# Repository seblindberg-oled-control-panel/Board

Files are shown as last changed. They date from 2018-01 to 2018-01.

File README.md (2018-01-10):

# OLED Control Panel Board

Mechanical design front
Mechanical design side

## Revisions

Board revisions are kept as tags in git. The board is generally tagged when the files have been sent off for manufacturing. To export a specific revision, simply run

```
$ git archive --format zip -o /path/to/rev-a.zip 9e7148
```

where the hash of the tag can be found by running `git show rev-a` for the specific tag.

## Scripts

A ruby script is included for generating EAGLE commands that place some of the more repetitive components. There are tools in EAGLE for achieving the same thing and they are most likely better, but a) I did not know that at the time and b) doing it yourself is often more flexible. 

To run the scripts you need to locate the Scripts folder in your terminal of choice and type `ruby place_leds.rb`. Then press `enter` and copy the output into the command input in EAGLE.

## Docs

The documentation is located in another repository and included here as a submodule. To get it after cloning you need to run

```
$ git submodule init
$ git submodule update
```

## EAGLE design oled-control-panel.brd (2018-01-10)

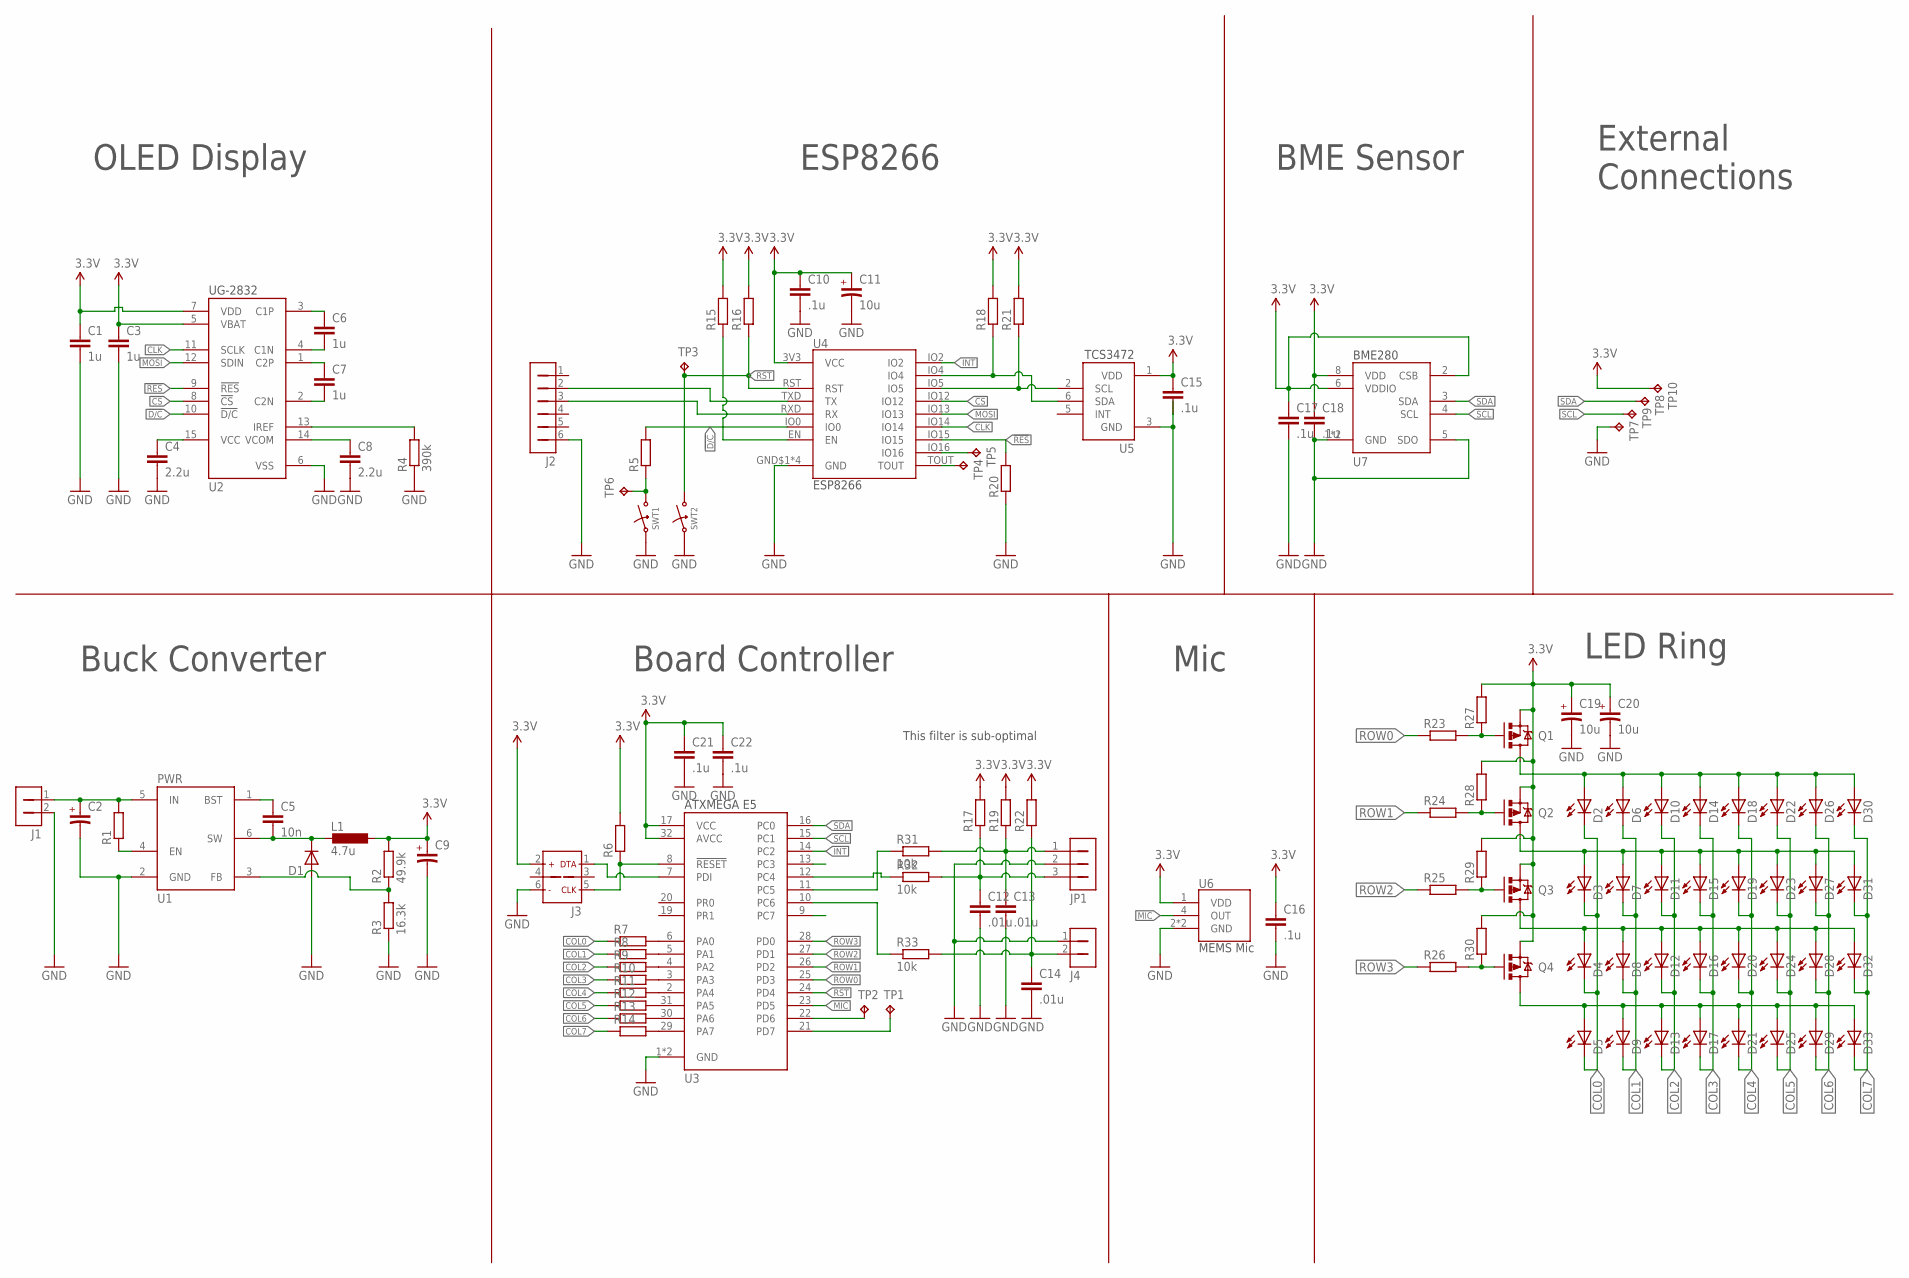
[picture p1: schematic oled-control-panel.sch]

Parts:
C1, C3, C6, C7: 1u; 0805
C2, C9: C_POL_1206; 1206_POL
C4, C8: 2.2u; 0805
C5: 10n; 0805
C10, C15, C16, C17, C18, C21, C22: .1u; 0603
C11, C19, C20: 10u; 1206_POL
C12, C13, C14: .01u; 0805
D1: D_FM581X; DO-214AC
D2, D3, D4, D5, D6, D7, D8, D9, D10, D11, D12, D13, D14, D15, D16, D17, D18, D19, D20, D21, D22, D23, D24, D25, D26, D27, D28, D29, D30, D31, D32, D33: LED_0805; 0805_LED
J1, J4: 1X2_MOLEX_53254
J2: 1X6_SMD_RIGHT
J3: PDI_SMD; ISP_SMD
JP1: 1X3_MOLEX_53254
L1: 4.7u; 1210
Q1, Q2, Q3, Q4: PMV160UP; SOT23
R1: R_0805; 0805
R2: 49.9k; 0805
R3: 16.3k; 0805
R4: 390k; 0805
R5, R6, R7, R8, R9, R10, R11, R12, R13, R14, R15, R16, R17, R18, R19, R20, R21, R22, R23, R24, R25, R26, R27, R28, R29, R30: R_0603; 0603
R31, R32, R33: 10k; 0603
SWT1, SWT2: BUTTON_SMD_2P; BTN_SMD_2PIN
TP1, TP2, TP3, TP4, TP5, TP6, TP7, TP8, TP9, TP10: TPTP15R; TP15R
U1: AP3211; SOT23-6
U2: UG-2832HSWEG04
U3: ATXMEGA_E5_TQFP; TQFP32
U4: ESP8266_13; ESP13
U5: TCS3472
U6: SPW2430HR5H_B
U7: BME280

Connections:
3.3V: C1.1, C3.1, C9.1, C10.1, C11.1, C15.1, C16.1, C17.1, C18.1, C19.1, C20.1, C21.1, C22.1, J3.2 (VCC), L1.2, Q1.2 (S), Q2.2 (S), Q3.2 (S), Q4.2 (S), R2.2, R6.2, R15.2, R16.2, R17.2, R18.2, R19.2, R21.2, R22.2, R27.2, R28.2, R29.2, R30.2, TP10.TP, U2.5 (VBAT), U2.7 (VDD), U3.17 (VCC), U3.32 (AVCC), U4.3V3 (VCC), U5.1 (VDD), U6.1 (VDD), U7.2 (CSB), U7.6 (VDDIO), U7.8 (VDD)
!CS: U2.8 (!CS), U4.IO12
!D/C: R5.2, U2.10 (!D/C), U4.IO0
!RES: R20.2, U2.9 (!RES), U4.IO15
A: C12.1, JP1.3, R17.1, R32.2
B: R31.1, U3.11 (PC5)
BTN: C14.1, J4.2, R22.1, R33.2
CLK: U2.11 (SCLK), U4.IO14
COL0: D2.C, D3.C, D4.C, D5.C, R7.1
COL1: D6.C, D7.C, D8.C, D9.C, R8.1
COL2: D10.C, D11.C, D12.C, D13.C, R9.1
COL3: D14.C, D15.C, D16.C, D17.C, R10.1
COL4: D18.C, D19.C, D20.C, D21.C, R11.1
COL5: D22.C, D23.C, D24.C, D25.C, R12.1
COL6: D26.C, D27.C, D28.C, D29.C, R13.1
COL7: D30.C, D31.C, D32.C, D33.C, R14.1
GND: C1.2, C2.2, C3.2, C4.2, C8.2, C9.2, C10.2, C11.2, C12.2, C13.2, C14.2, C15.2, C16.2, C17.2, C18.2, C19.2, C20.2, C21.2, C22.2, D1.A, J1.2, J2.6, J3.6 (GND), J4.1, JP1.2, R3.1, R4.1, R20.1, SWT1.1, SWT2.1, TP7.TP, U1.2 (GND), U2.6 (VSS), U3.1 (GND), U3.18 (GND), U4.GND$1 (GND), U4.GND$2 (GND), U4.GND$3 (GND), U4.GND$4 (GND), U5.3 (GND), U6.2 (GND), U6.3 (GND), U7.1 (GND), U7.5 (SDO), U7.7 (GND)
INT: U3.14 (PC2), U4.IO2
MIC: U3.23 (PD5), U6.4 (OUT)
MOSI: U2.12 (SDIN), U4.IO13
unnamed: C6.1, U2.3 (C1P)
unnamed: C6.2, U2.4 (C1N)
unnamed: C7.1, U2.1 (C2P)
unnamed: C7.2, U2.2 (C2N)
unnamed: R4.2, U2.13 (IREF)
unnamed: C8.1, U2.14 (VCOM)
unnamed: C2.1, J1.1, R1.2, U1.5 (IN)
unnamed: C5.1, U1.1 (BST)
unnamed: C4.1, U2.15 (VCC)
unnamed: C5.2, D1.C, L1.1, U1.6 (SW)
unnamed: R2.1, R3.2, U1.3 (FB)
unnamed: R1.1, U1.4 (EN)
unnamed: J3.5 (CLK), R6.1, U3.8 (!RESET)
unnamed: Q1.1 (G), R23.2, R27.1
unnamed: Q2.1 (G), R24.2, R28.1
unnamed: Q3.1 (G), R25.2, R29.1
unnamed: Q4.1 (G), R26.2, R30.1
unnamed: J3.1 (DATA), U3.7 (PDI)
unnamed: R7.2, U3.6 (PA0)
unnamed: R8.2, U3.5 (PA1)
unnamed: D3.A, D7.A, D11.A, D15.A, D19.A, D23.A, D27.A, D31.A, Q2.3 (D)
unnamed: D4.A, D8.A, D12.A, D16.A, D20.A, D24.A, D28.A, D32.A, Q3.3 (D)
unnamed: D5.A, D9.A, D13.A, D17.A, D21.A, D25.A, D29.A, D33.A, Q4.3 (D)
unnamed: D2.A, D6.A, D10.A, D14.A, D18.A, D22.A, D26.A, D30.A, Q1.3 (D)
unnamed: R9.2, U3.4 (PA2)
unnamed: R10.2, U3.3 (PA3)
unnamed: R11.2, U3.2 (PA4)
unnamed: R12.2, U3.31 (PA5)
unnamed: R13.2, U3.30 (PA6)
unnamed: R14.2, U3.29 (PA7)
unnamed: R5.1, SWT1.2, TP6.TP
unnamed: TP5.TP, U4.IO16
unnamed: J2.2, U4.TXD (TX)
unnamed: J2.3, U4.RXD (RX)
unnamed: R15.1, U4.EN
unnamed: R32.1, U3.12 (PC4)
unnamed: R33.1, U3.10 (PC6)
unnamed: C13.1, JP1.1, R19.1, R31.2
unnamed: TP4.TP, U4.TOUT
unnamed: TP2.TP, U3.22 (PD6)
unnamed: TP1.TP, U3.21 (PD7)
ROW0: R23.1, U3.25 (PD3)
ROW1: R24.1, U3.26 (PD2)
ROW2: R25.1, U3.27 (PD1)
ROW3: R26.1, U3.28 (PD0)
RST: R16.1, SWT2.2, TP3.TP, U3.24 (PD4), U4.RST
SCL: R21.1, TP9.TP, U3.15 (PC1), U4.IO5, U5.2 (SCL), U7.4 (SCL)
SDA: R18.1, TP8.TP, U3.16 (PC0), U4.IO4, U5.6 (SDA), U7.3 (SDA)

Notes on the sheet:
ESP8266
BME Sensor
LED Ring
Board Controller
Buck Converter
OLED Display
Mic
External Connections
This filter is sub-optimal

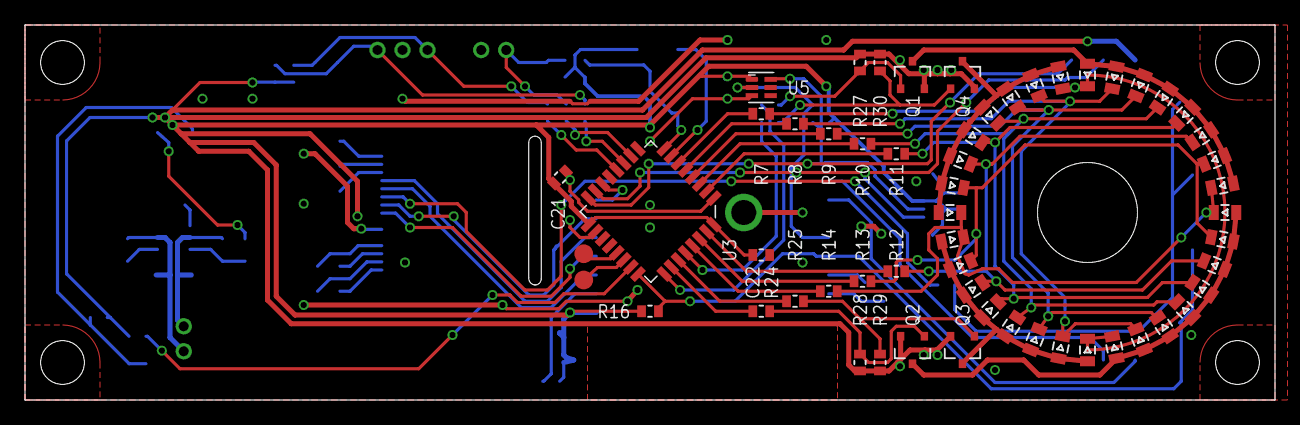
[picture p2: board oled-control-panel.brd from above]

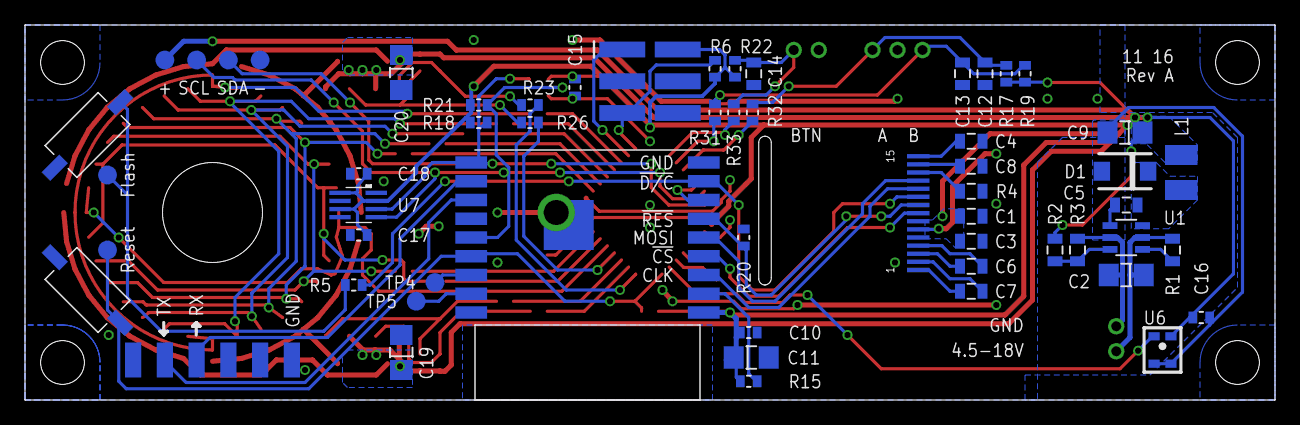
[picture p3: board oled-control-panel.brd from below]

Board: 2 copper layers, 100.0 x 30.0 mm, 117 parts (60 on the bottom side), 68 nets.

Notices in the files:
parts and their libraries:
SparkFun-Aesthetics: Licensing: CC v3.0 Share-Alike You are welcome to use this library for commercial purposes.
